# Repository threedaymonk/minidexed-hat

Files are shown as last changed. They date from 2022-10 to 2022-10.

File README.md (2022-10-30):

# MiniDexed Hat for Raspberry Pi

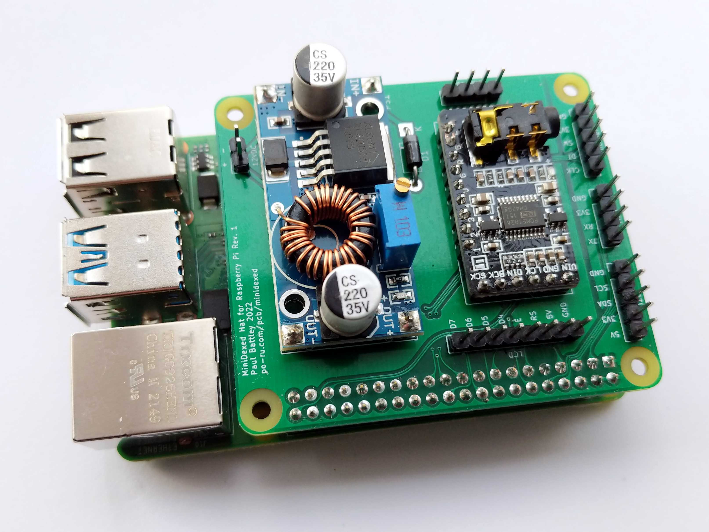
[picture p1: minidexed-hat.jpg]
Board mounted on Raspberry Pi 4


This aims to make the construction of a
[MiniDexed](https://github.com/probonopd/MiniDexed) a little easier.

Features:

- On-board step-down converter to run from a typical 12V wall-wart power supply
  to sidestep the exacting USB-C requirements of the Raspberry Pi 4
- Direct mounting for a PCM5102A audio module, with output routed to headers
- Headers for connecting peripherals:
  - 8 pins for a 1602 display (using [this backpack
    board](https://po-ru.com/pcb/1602))
  - I2C for an OLED display
  - Left and right line out
  - Serial MIDI for a [3.3V MIDI interface](https://po-ru.com/pcb/midi)
  - KY-040 encoder module

Revision 1 does not include debouncing capacitors for the encoder. I intend to
make my own encoder boards with better debouncing.

The PCB dimensions are based on [Seth Hillbrand's
template](https://github.com/sethhillbrand/kicad_templates) for a Raspberry Pi
hat.

With an appropriate display, this board should also work with
[mt32-pi](https://github.com/dwhinham/mt32-pi), but I have not tested it.

## Warning

Set the voltage on the converter **before** soldering the audio interface in
place or installing the hat on the Pi. I recommend around 5.2V.

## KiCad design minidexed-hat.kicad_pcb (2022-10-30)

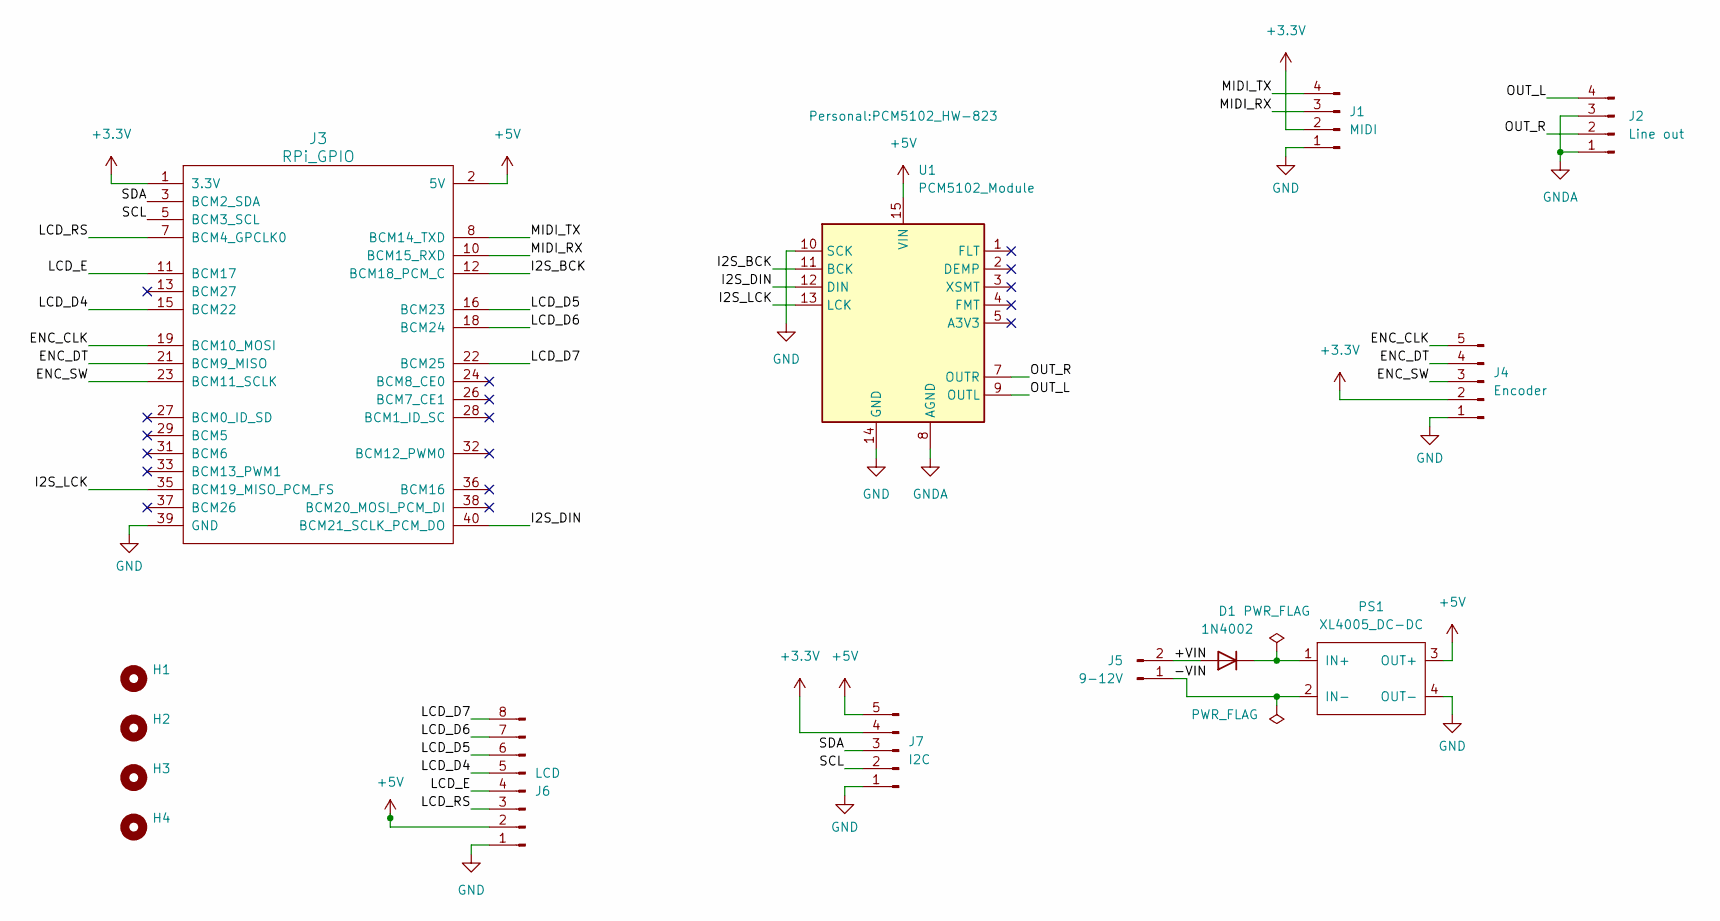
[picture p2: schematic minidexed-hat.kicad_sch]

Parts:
D1: 1N4002; D_DO-41_SOD81_P10.16mm_Horizontal
H1, H2, H3, H4: RPi_Hat_Mounting_Hole
J1: MIDI; PinHeader_1x04_P2.54mm_Vertical
J2: Line out; PinHeader_1x04_P2.54mm_Vertical
J3: RPi_GPIO; PinSocket_2x20_P2.54mm_Vertical
J4: Encoder; PinHeader_1x05_P2.54mm_Vertical
J5: 9-12V; PinHeader_1x02_P2.54mm_Vertical
J6: LCD; PinHeader_1x08_P2.54mm_Vertical
J7: I2C; PinHeader_1x05_P2.54mm_Vertical
PS1: XL4005_DC-DC
U1: PCM5102_Module; PCM5102_HW-823

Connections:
+3.3V: J1.2, J3.1 (3.3V), J3.17 (3.3V), J4.2, J7.4
+5V: J3.2 (5V), J3.4 (5V), J6.2, J7.5, PS1.3 (OUT+), U1.15 (VIN)
/+VIN: D1.2 (A), J5.2
/-VIN: J5.1, PS1.2 (IN-)
/ENC_CLK: J3.19 (BCM10_MOSI), J4.5
/ENC_DT: J3.21 (BCM9_MISO), J4.4
/ENC_SW: J3.23 (BCM11_SCLK), J4.3
/I2S_BCK: J3.12 (BCM18_PCM_C), U1.11 (BCK)
/I2S_DIN: J3.40 (BCM21_SCLK_PCM_DO), U1.12 (DIN)
/I2S_LCK: J3.35 (BCM19_MISO_PCM_FS), U1.13 (LCK)
/LCD_D4: J3.15 (BCM22), J6.5
/LCD_D5: J3.16 (BCM23), J6.6
/LCD_D6: J3.18 (BCM24), J6.7
/LCD_D7: J3.22 (BCM25), J6.8
/LCD_E: J3.11 (BCM17), J6.4
/LCD_RS: J3.7 (BCM4_GPCLK0), J6.3
/MIDI_RX: J1.3, J3.10 (BCM15_RXD)
/MIDI_TX: J1.4, J3.8 (BCM14_TXD)
/OUT_L: J2.4, U1.9 (OUTL)
/OUT_R: J2.2, U1.7 (OUTR)
/SCL: J3.5 (BCM3_SCL), J7.2
/SDA: J3.3 (BCM2_SDA), J7.3
GND: J1.1, J3.6 (GND), J3.9 (GND), J3.14 (GND), J3.20 (GND), J3.25 (GND), J3.30 (GND), J3.34 (GND), J3.39 (GND), J4.1, J6.1, J7.1, PS1.4 (OUT-), U1.10 (SCK), U1.14 (GND)
GNDA: J2.1, J2.3, U1.6 (AGND), U1.8 (AGND)
unnamed: D1.1 (K), PS1.1 (IN+)

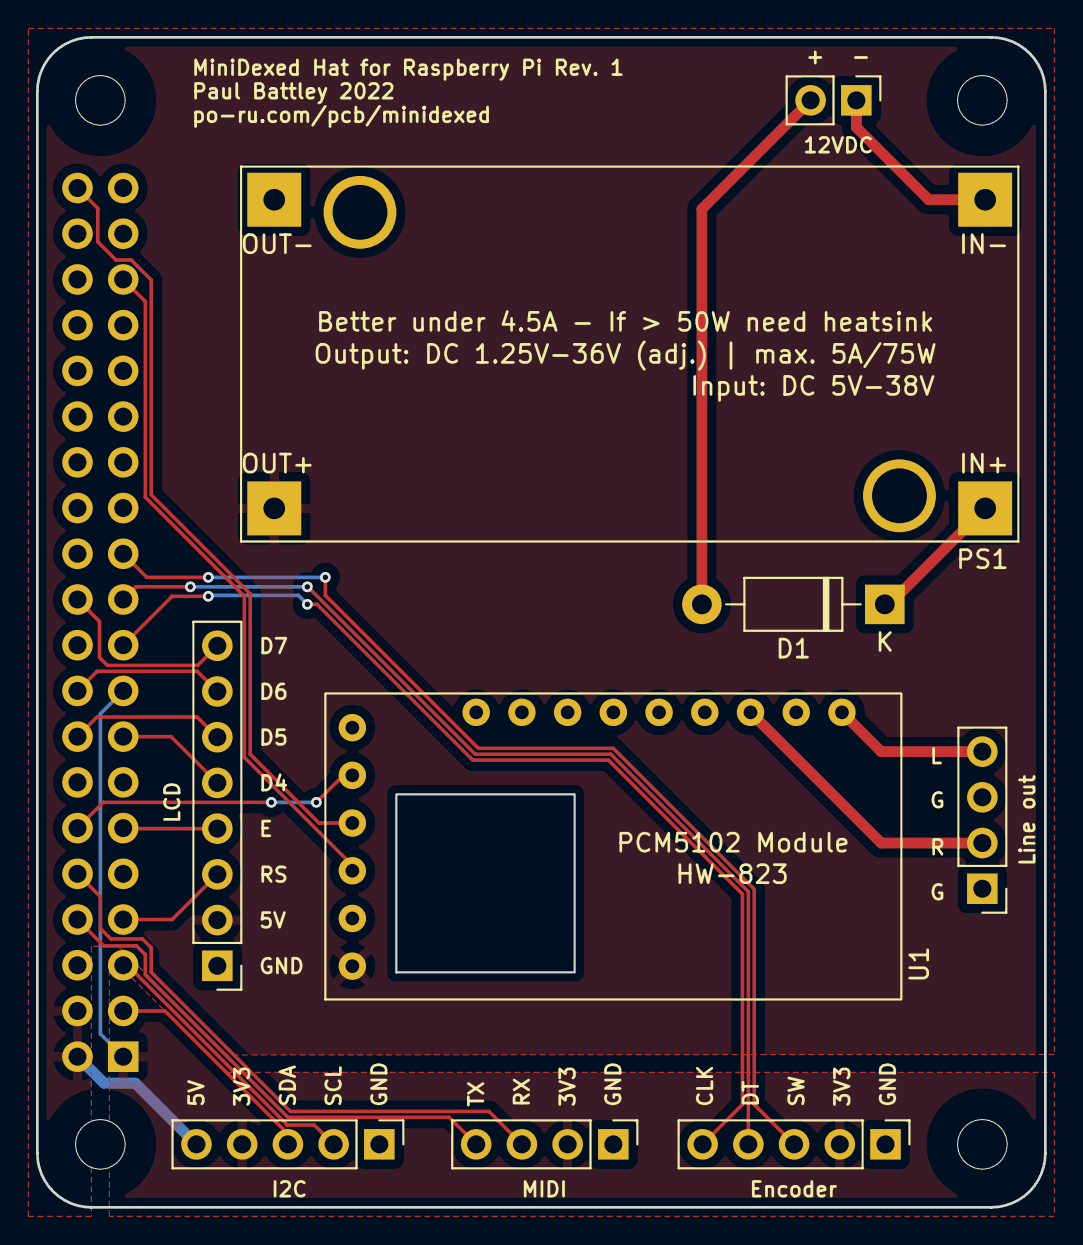
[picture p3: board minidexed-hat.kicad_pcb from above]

Board: 2 copper layers, 56.0 x 65.0 mm, 14 parts (1 on the bottom side), 25 nets.

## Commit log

2022-10-13 Create new repo for my template
    This is based on https://github.com/sethhillbrand/kicad_templates
    updated to Kicad 6 and using A4 paper.
    [JLCPCB_Template.kicad_pcb, JLCPCB_Template.kicad_sch]
2022-10-13 Import basic PCB shape
    From https://github.com/devbisme/RPi_Hat_Template
    [JLCPCB_Template.kicad_pcb, JLCPCB_Template.kicad_sch, minidexed-hat.kicad_pcb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]
2022-10-30 Complete with MIDI and connectors off-board
    [midi.kicad_sch, minidexed-hat.kicad_pcb, minidexed-hat.kicad_sch]
2022-10-30 Tweak tracks to preserve spacing when rounding
    [minidexed-hat.kicad_pcb]
2022-10-30 Add text
    [minidexed-hat.kicad_pcb]
2022-10-30 Add placeholder for order number
    [minidexed-hat.kicad_pcb]
2022-10-30 Save rounded track configuration
2022-10-30 Add warning about power
